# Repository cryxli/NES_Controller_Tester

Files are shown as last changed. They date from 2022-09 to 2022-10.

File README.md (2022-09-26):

# NES Controller Tester

 > When fixing and refurbishing S/NES controllers, I need a way to quickly test the buttons. Games are usually not that useful, since you have to start something before you can test all buttons. To save me fiddling with potentially buggy consoles, I desinged my own tester.
>
> ~ cryxli, August 2022

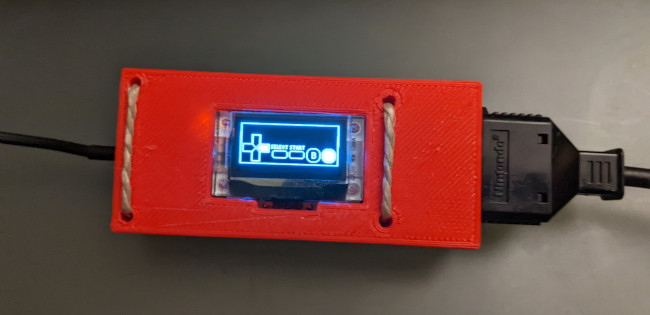
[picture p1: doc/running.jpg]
Running


Finished project showing some pressed buttons, powered by a USB power bank, held together with string.

## Project Overview

You do not have to go the extra mile to make the project modular. By doing so you save on Dupont headers, but have to scope with an increased risk of damaging the ESP.

### Repository

- ``/doc`` - Contains files for the documentation.
- ``/NES_controller_tester`` - Contains the [Arduino](https://www.arduino.cc) source code. Open this folder in the IDE.
- ``/pcb`` - Contains the [Sprint Layout 6](https://www.electronic-software-shop.com/lng/en/electronic-software/sprint-layout-60.html?language=en) design of the base plate.
- ``/scad`` - Contains the [OpenSCAD](https://openscad.org) design for the enclosure.

### Parts

- NES controller socket with straight pins
- [Heltec Wifi Kit 32, with OLED display](https://heltec-automation-docs.readthedocs.io/en/latest/esp32/quick_start.html)
- Straight and angled pin headers and sockets
- 5 pin Dupont connector
- 3 pin Dupont connector
- Dupont female crimps
- USB lead

### Tools

- Soldering equipment (iron, solder, flux)
- Pliers for Dupont crimps
- Computer with [Arduino](https://www.arduino.cc) IDE to flash the ESP
- NES controller and UBS power bank for testing

## S/NES Controller Pinout

NES and SNES controllers work exactly the same. Because both are keyed (they are asymmetrical) there is no need to distingush between front or back, socket or connector view.

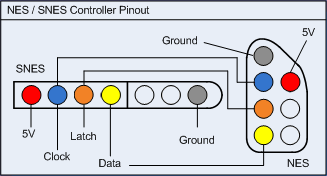
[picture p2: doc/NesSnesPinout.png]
Pinout


- ``RED`` := 5V
- ``GRAY`` := GND
- ``BLUE`` := Clock (active low)
- ``ORANGE`` := Latch (active high)
- ``YELLOW`` := Data (active low)
- ``WHITE`` := unused by standard controllers

"Active low" means a locigal ``1`` is represented by 0V. While with "active high" a logical ``1`` would be represented by about 3V or above.

## Protocol

The S/NES controllers use a serial protocol to transmit the state of the buttons to the console. That means a [Shift Register (PISO)](https://en.wikipedia.org/wiki/Shift_register#Parallel-in_serial-out_(PISO)) reads the state of the buttons and then sends them one by one over the DATA line to the console.

For that to happen the console must tell the controller to read the button states by setting LATCH high.

With every pulse of the CLOCK to low the next button state is set on the DATA line.

A button is pressed <=> Corresponding DATA is low.

## Shift Registers

The NES controllers have only one 8-bit shift register for their 8 buttons. The SNES controllers have 12 buttons and use two 8-bit shift registers chained together. 

The order in which the button states are transmitted differs

| Controller | T1  | T2  | T3 | T4 | T5  | T6 | T7 | T8 | T9  | T10 | T11 | T12 |
|:---|:---:|:---:|:---:|:-----:|:---:|:----:|:----:|:-----:|:---:|:---:|:---:|:---:|
| NES | A | B | Select | Start | Up  | Down | Left | Right | - | - | - | - |
| SNES | B | Y | Select | Start | Up  | Down | Left | Right | A | X | L | R |

[Shift registers](https://en.wikipedia.org/wiki/Shift_register) don't care how many times they are pulsed (CLOCK) to send the next bit. As long as they have data, they will answer before they eventually default to zeros.

Therefore, it should be possible to read both types of controller with the same piece of code that asks them for 16 bits of data.

## Display

[ESP8266](https://www.espressif.com/en/products/socs/esp8266) and later ESPs are overkill for reading S/NES controllers, but they constantly evolve. [Heltec Automation](https://heltec.org/) resently created a Devkit combined with an 128x64 pixel OLED display.

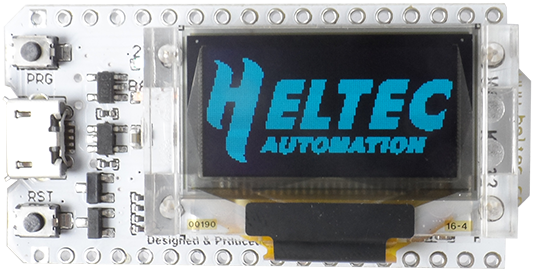
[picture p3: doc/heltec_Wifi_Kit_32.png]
Hiltec


They provide full support for the [Arduino](https://www.arduino.cc) development environment. Including a library to address the OLED display, complete with examples.

:bulb: [Setup Heltec ESP32 LoRa](https://heltec-automation-docs.readthedocs.io/en/latest/esp32/quick_start.html)

## Assembly

Most ESPs don't like it when you apply more than 3.3V on their input pins. To avoid that the controllers do that, let's drive them with only 3.3V from the board's voltage regulator.

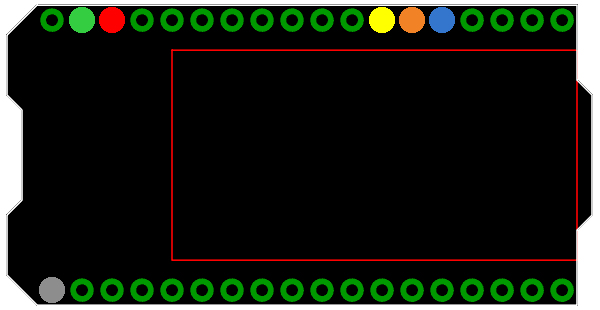
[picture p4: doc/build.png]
Build


The colored pins correspond to the colors used in the controller pinout, above. 

- ``GREEN`` = ``5V`` := Vin input voltage
- ``GRAY`` = ``GND`` := Ground or 0V reference for input voltage and connector circuit
- ``BLUE`` = ``18`` := Clock
- ``ORANGE`` = ``5`` := Latch
- ``YELLOW`` = ``17`` := Data
- ``RED`` = ``3V3`` := regulated 3.3V

The pins on the ESP board are not numbered like the legs of an IC. Look at a [pinout diagram](https://resource.heltec.cn/download/WiFi_Kit_32/WIFI_Kit_32_pinoutDiagram_V2.pdf) or the PCB, below.

## PCB

Note the gound pin next to the 5V input pin... I fried a board applying 5V using that pin as the 0V reference. To avoid future accidents I've drawn a base PCB in [Sprint Layout 6](https://www.electronic-software-shop.com/lng/en/electronic-software/sprint-layout-60.html?language=en). There is a free viewer on their site, too.

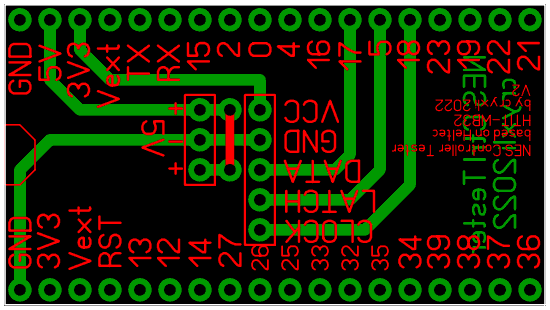
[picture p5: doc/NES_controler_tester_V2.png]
PCB


I also turned the design 180° to match the layout of the images above.

The idea is to have a 90° pin header expose the 5 connections for the controller and a 3 pin header for the power supply.

### 5V via USB

Whenever I cut off a USB lead and turn it into a 5V power supply for my projects, I add a 3 pin Dupond connector with center negative. By adding a link between the outer pins on the project/board, I do not have to worry about polarity anymore. 

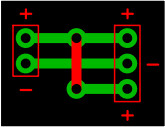
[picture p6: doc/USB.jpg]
5V USB


This comes from a time when I only used [Dupont](https://www.google.com/search?q=Dupont+connector) connectors that were *not* keyed.

## Enclosure

For the NES socket to fit in the 3d printed box, we have to cut off its studs at the bottom.

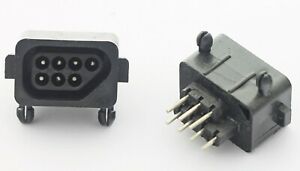
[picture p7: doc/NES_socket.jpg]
NES Socket


The design will hold it in place with the side tags only.

I use [OpenSCAD](https://openscad.org). Not only is it free, it also suits my way of designing best.

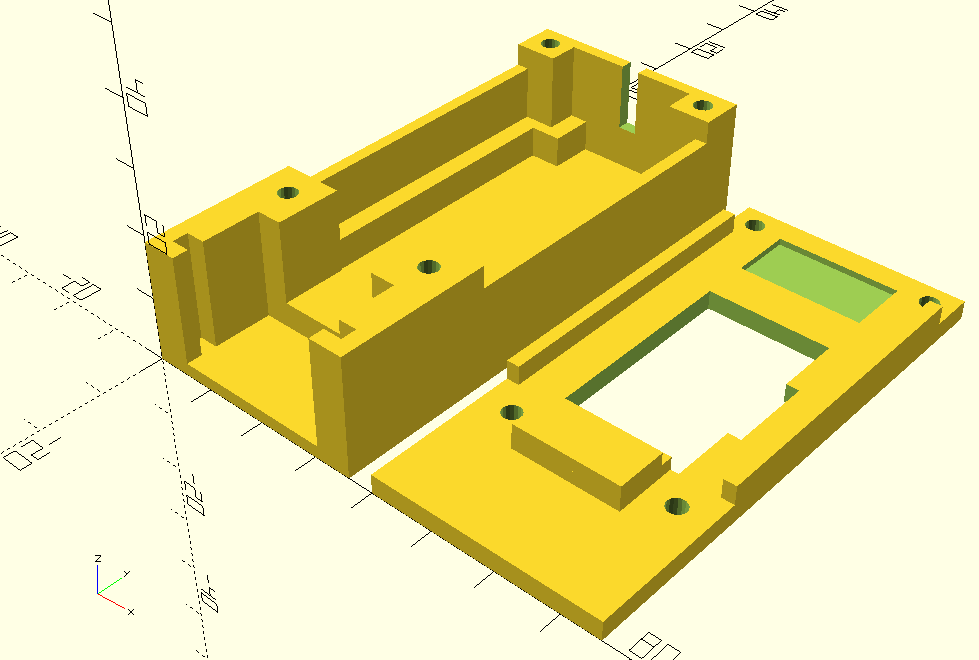
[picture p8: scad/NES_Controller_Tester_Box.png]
Enclosure


The lid is designed to register with the body. There should be less than 1/2 mm play with every component.

The box has holes for M3 bolts to hold it closed, but the friction fit of the interlocking lid is usually enough.

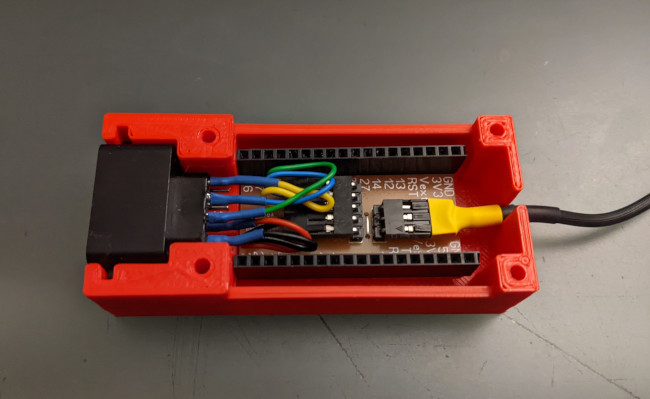
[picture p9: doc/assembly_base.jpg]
Assembly Base


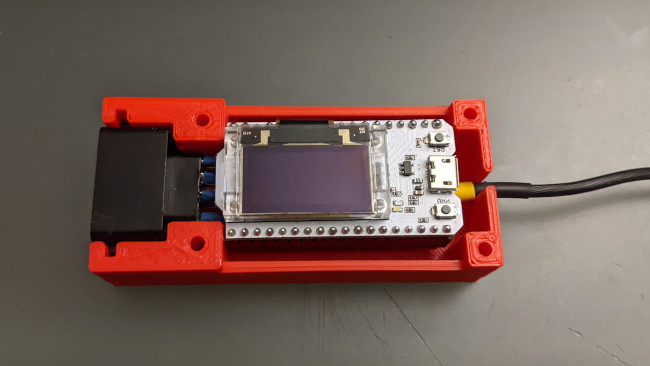
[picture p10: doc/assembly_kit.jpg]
Assembly Kit


Pay extra attention to the OLED display when closing the lid! The top glass layer is very thin and breaks easily. 

# Resources

Some helpful links:

- [Wifi Kit 32](https://heltec.org/project/wifi-kit-32/)
  - [Pinout](https://resource.heltec.cn/download/WiFi_Kit_32/WIFI_Kit_32_pinoutDiagram_V2.pdf)
- [Sprint Layout 6](https://www.electronic-software-shop.com/lng/en/electronic-software/sprint-layout-60.html?language=en)
  - [Viewer](https://www.electronic-software-shop.com/support/kostenlose-datei-viewer/)
- [OpenSCAD](https://openscad.org)
  - [User Manual](https://en.wikibooks.org/wiki/OpenSCAD_User_Manual)

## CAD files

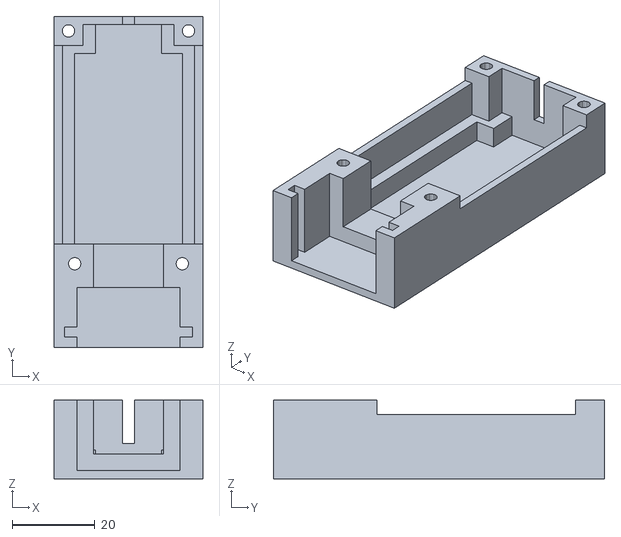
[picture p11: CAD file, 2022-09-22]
scad/NES_Controller_Tester_Box_body.stl
36.0 x 80.0 x 19.0

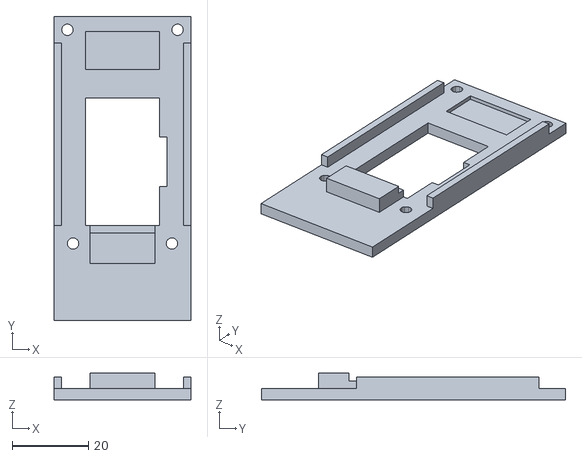
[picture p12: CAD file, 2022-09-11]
scad/NES_Controller_Tester_Box_lid.stl
36.0 x 80.0 x 7.00

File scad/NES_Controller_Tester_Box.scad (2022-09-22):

// -----------------------------------------
// NES Controller Tester
// by cryxli, August 2022
// -----------------------------------------

base_plate = 2;     // [mm] How strong to make the bottom of the box
depth = 25;         // [mm] How far the socket reaches into the box
height = 17;        // [mm] Height of the socket
oled_width = 19.5;  // [mm] Width of the OLED display
oled_length = 33.5; // [mm] Length od the OLED display
$fn = 18;           // [faces] Make circles 18 sided polys

// The body of the box
difference() {
	union() {
		// base
		cube([36,depth+48+2+5,base_plate]);
		
		// left side of socket
		cube([5.5,2.5,base_plate+height]);
		cube([2.5,10,base_plate+height]);
		translate([0,5,0]) cube([5.5,depth-5,base_plate+height]);
		translate([0,14.5,0]) cube([9.5,depth-14.5,base_plate+height]);
		
		// right side of socket
		translate([30.5,0,0]) {
			cube([5.5,2.5,base_plate+height]);
			translate([3,0,0]) cube([2.5,10,base_plate+height]);
			translate([0,5,0]) cube([5.5,depth-5,base_plate+height]);
			translate([-4,14.5,0]) cube([9.5,depth-14.5,base_plate+height]);
		}
		// bottom support for socket
		translate([0,14.5,0]) cube([36,depth-14.5,base_plate+4]);
		
		// back of box
		translate([0,depth+53,0]) cube([36,2,base_plate+height]);
		translate([0,depth+48,0]) cube([7,7,base_plate+height]);
		translate([29,depth+48,0]) cube([7,7,base_plate+height]);
		
		// side
		cube([2,depth+48+2+5,base_plate+height-3.5]);
		translate([0,7,0]) cube([5,depth+48,base_plate+5]);
		// opposite side
		translate([34,0,0]) cube([2,depth+48+2+5,base_plate+height-3.5]);
		translate([31,7,0]) cube([5,depth+48,base_plate+5]);

		// back stop for PCB
		translate([0,depth+46,0]) cube([10,9,base_plate+5]);
		translate([26,depth+46,0]) cube([10,9,base_plate+5]);
	}
	
	// M3 holes behind the socket
	translate([5,depth-4.75,-1]) cylinder(d=3, h=base_plate+height+2);
	translate([31,depth-4.75,-1]) cylinder(d=3, h=base_plate+height+2);
	// M3 holes at the end of the box
	translate([2+1.5,depth+48+2+1.5,-1]) cylinder(d=3, h=base_plate+height+2);
	translate([31+1.5,depth+48+2+1.5,-1]) cylinder(d=3, h=base_plate+height+2);
	
	// slit for USB lead
	translate([(36-3)/2,depth+48+2+5-3,height/2]) cube([3,4,height]);
}


// The lid
translate([40,0,0]) difference() {
	union() {
		// base
		cube([36,depth+48+2+5,3]);
		// register and hold-down for socket
		translate([(36-17)/2,15,0]) cube([17,8,3+4]);
		// with register for ESP
		translate([(36-17)/2,15,0]) cube([17,10,3+2]);
		
		// interlocking sides (0.5mm gap is intentional)
		translate([0,depth,0]) cube([2,48,6]);
		translate([36-2,depth,0]) cube([2,48,6]);
	}
	// space for the micro USB connector and buttons
	translate([(36-oled_width)/2,depth+48+5-12,2]) cube([oled_width,10,2]);

	// hole for OLED display and its ribbon
	translate([(36-oled_width)/2,depth,-1]) cube([oled_width,oled_length,5]);
	translate([(36-oled_width)/2+oled_width-1,depth + (oled_length-13)/2,-1]) cube([3,13,5]);

	// M3 holes behind the socket
	translate([5,depth-4.75,-1]) cylinder(d=3, h=5);
	translate([31,depth-4.75,-1]) cylinder(d=3, h=5);
	// M3 holes at the end of the box
	translate([2+1.5,depth+48+2+1.5,-1]) cylinder(d=3, h=5);
	translate([31+1.5,depth+48+2+1.5,-1]) cylinder(d=3, h=5);
}

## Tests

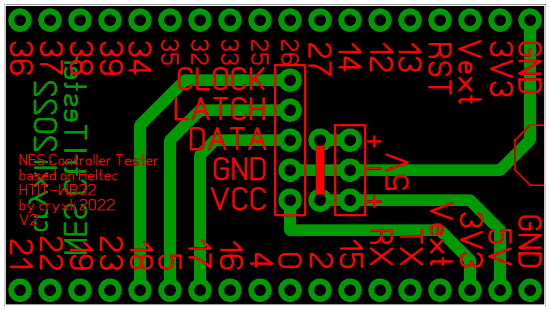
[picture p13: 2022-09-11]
pcb/NES_controler_tester_V2.png

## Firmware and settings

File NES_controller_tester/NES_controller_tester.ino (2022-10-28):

// -------------------------------------------------
// NES Controller Tester, v2.0
// by cryxli, August 2022
// 
// Based on a Heltec Wifi Kit 32 with a 128x64 pixel
// OLED display.
//
// This version supports NES and SNES controllers.
// -------------------------------------------------
#include "Arduino.h"
#include "heltec.h"

// include our bitmaps for the controller layout and buttons
#include "nes.h"
#include "snes.h"

// pins for communication with controller
//      5V          red
//      GND         black
#define DATA  17 // yellow
#define LATCH  5 // blue
#define CLOCK 18 // green

// define some delays [ms]
#define LATCH_DELAY 5
#define PULSE_DELAY 1
#define CLOCK_DELAY 5
#define DATA_DELAY 5
#define LOOP_DELAY 20

// bitmap masks for the NES buttons
#define NES_A      1<<7
#define NES_B      1<<6
#define NES_SELECT 1<<5
#define NES_START  1<<4
#define NES_UP     1<<3
#define NES_DOWN   1<<2
#define NES_LEFT   1<<1
#define NES_RIGHT  1<<0

// bitmap masks for the SNES buttons
#define SNES_B      1<<11
#define SNES_Y      1<<10
#define SNES_SELECT 1<<9
#define SNES_START  1<<8
#define SNES_UP     1<<7
#define SNES_DOWN   1<<6
#define SNES_LEFT   1<<5
#define SNES_RIGHT  1<<4
#define SNES_A      1<<3
#define SNES_X      1<<2
#define SNES_L      1<<1
#define SNES_R      1<<0

// you can set LoRa band directly, e.g. 868E6,915E6
#define BAND 868E6 

void setup() {
    // define pins
    pinMode(DATA, INPUT);
    pinMode(LATCH, OUTPUT);
    pinMode(CLOCK, OUTPUT);
    // set default state
    digitalWrite(LATCH, LOW);
    digitalWrite(CLOCK, HIGH);

    // init OLED etc.
    Heltec.begin(
        true  /* DisplayEnable Enable*/, 
        false /* LoRa Enable         */, 
        true  /* Serial Enable       */, 
        false /* LoRa use PABOOST    */, 
        BAND  /* LoRa RF working band*/
    );
}

/**
 * Quickly change the state of an output pin, then revert to stand-by.
 */
void pulseWire(int wire, bool pulse) {
    if (pulse == 1) {
        digitalWrite(wire, HIGH);
        delay(PULSE_DELAY);
        digitalWrite(wire, LOW);
    } else {
        digitalWrite(wire, LOW);
        delay(PULSE_DELAY);
        digitalWrite(wire, HIGH);
    }
}

void loop() {
    // have controller read button states
    pulseWire(LATCH, 1);
    delay(DATA_DELAY);

    //  NES buttons: A, B, SELECT, START, UP, DOWN, LEFT, RIGHT
    // SNES buttons: B, Y, SELECT, START, UP, DOWN, LEFT, RIGHT, A, X, L, R
    int buttons = 0;
    for(int index = 1<<15; index > 0; index = index >> 1) {
        buttons = (buttons << 1) + 1 - digitalRead(DATA);
        pulseWire(CLOCK, 0);
        delay(DATA_DELAY);
    }
    // for debugging
    // Serial.print("Buttons: ");
    // Serial.println(buttons);

    // display the result
    if (buttons & 15 > 0) {
        displayNoControllerConnected();
    } else if (buttons & 255 > 0) {
        displayNesButtons(buttons>>8);
    } else {
        displaySnesButtons(buttons>>4);
    }

    delay(LOOP_DELAY);
}

/**
 * "All" buttons are pressed, therefore no controller is connected. Show a
 * hint to connect a controller.
 */
void displayNoControllerConnected() {
    // reset display buffer
    Heltec.display -> clear();
    // draw the empty controller layout
//    Heltec.display -> drawXbm(0, 0, NES_Layout_width, NES_Layout_height, NES_Layout_bits);
    // show hint
    Heltec.display -> drawString(10, 5, "Connect a controller...");

    Heltec.display -> drawString(10, 25, "Support for NES and");
    Heltec.display -> drawString(10, 35, "SNES controllers.");

    Heltec.display -> drawString(10, 50, "v2.0");
    Heltec.display -> drawString(80, 50, "by cryxli");
    
    // update display
    Heltec.display -> display();
}

/**
 * Graphically show which NES buttons are pressed
 */
void displaySnesButtons(int buttons) {
    // display pressed buttons; reset display buffer
    Heltec.display -> clear();
    // draw the empty controller layout
    Heltec.display -> drawXbm(0, 0, SNES_Layout_width, SNES_Layout_height, SNES_Layout_bits);

    // highlight pressed buttons
    if ((buttons & SNES_UP) > 0) {
        Heltec.display -> drawXbm(17, 17, NES_up_width, NES_up_height, NES_up_bits);
    }
    if ((buttons & SNES_LEFT) > 0) {
        Heltec.display -> drawXbm(3, 29, NES_left_width, NES_left_height, NES_left_bits);
    }
    if ((buttons & SNES_RIGHT) > 0) {
        Heltec.display -> drawXbm(22, 29, NES_right_width, NES_right_height, NES_right_bits);
    }
    if ((buttons & SNES_DOWN) > 0) {
        Heltec.display -> drawXbm(17, 35, NES_down_width, NES_down_height, NES_down_bits);
    }
    if ((buttons & SNES_SELECT) > 0) {
        Heltec.display -> fillRect(44, 37, 16, 6);
    }
    if ((buttons & SNES_START) > 0) {
        Heltec.display -> fillRect(66, 37, 16, 6);
    }
    if ((buttons & SNES_L) > 0) {
        Heltec.display -> fillRect(0, 0, 12, 6);
    }
    if ((buttons & SNES_R) > 0) {
        Heltec.display -> fillRect(116, 0, 12, 6);
    }
    if ((buttons & SNES_Y) > 0) {
        Heltec.display -> fillRect(89, 27, 9, 9);
    }
    if ((buttons & SNES_X) > 0) {
        Heltec.display -> fillRect(101, 15, 9, 9);
    }
    if ((buttons & SNES_B) > 0) {
        Heltec.display -> fillRect(101, 39, 9, 9);
    }
    if ((buttons & SNES_A) > 0) {
        Heltec.display -> fillRect(113, 27, 9, 9);
    }
    // done, update display
    Heltec.display -> display();
}

/**
 * Graphically show which SNES buttons are pressed
 */
void displayNesButtons(int buttons) {
    // display pressed buttons; reset display buffer
    Heltec.display -> clear();
    // draw the empty controller layout
    Heltec.display -> drawXbm(0, 0, NES_Layout_width, NES_Layout_height, NES_Layout_bits);
    // highlight pressed buttons
    if ((buttons & NES_UP) > 0) {
        Heltec.display -> drawXbm(17, 17, NES_up_width, NES_up_height, NES_up_bits);
    }
    if ((buttons & NES_LEFT) > 0) {
        Heltec.display -> drawXbm(3, 29, NES_left_width, NES_left_height, NES_left_bits);
    }
    if ((buttons & NES_RIGHT) > 0) {
        Heltec.display -> drawXbm(22, 29, NES_right_width, NES_right_height, NES_right_bits);
    }
    if ((buttons & NES_DOWN) > 0) {
        Heltec.display -> drawXbm(17, 35, NES_down_width, NES_down_height, NES_down_bits);
    }
    if ((buttons & NES_SELECT) > 0) {
        Heltec.display -> fillRect(44, 37, 16, 6);
    }
    if ((buttons & NES_START) > 0) {
        Heltec.display -> fillRect(66, 37, 16, 6);
    }
    if ((buttons & NES_B) > 0) {
        Heltec.display -> drawXbm(89, 33, NES_a_width, NES_a_height, NES_a_bits);
    }
    if ((buttons & NES_A) > 0) {
        Heltec.display -> drawXbm(109, 33, NES_a_width, NES_a_height, NES_a_bits);
    }
    // done, update display
    Heltec.display -> display();
}

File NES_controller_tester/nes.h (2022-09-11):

// -------------------------------------------------
// NES Controller Tester
// by cryxli, August 2022
// 
// Based on a Heltec Wifi Kit 32 with a 128x64 pixel
// OLED display.
//
// This file contains the bitmaps for the NES
// controller layout including pressed buttons.
// -------------------------------------------------

// empty controller layout
#define NES_Layout_width 128
#define NES_Layout_height 53

const unsigned char NES_Layout_bits[] PROGMEM = {
    0xff,0xff,0xff,0xff,0xff,0xff,0xff,0xff,0xff,0xff,0xff,0xff,0xff,0xff,0xff,0xff,
    0x01,0x00,0x00,0x00,0x00,0x00,0x00,0x00,0x00,0x00,0x00,0x00,0x00,0x00,0x00,0x80,
    0x01,0x00,0x00,0x00,0x00,0x00,0x00,0x00,0x00,0x00,0x00,0x00,0x00,0x00,0x00,0x80,
    0x01,0x00,0x00,0x00,0x00,0x00,0x00,0x00,0x00,0x00,0x00,0x00,0x00,0x00,0x00,0x80,
    0x01,0x00,0x00,0x00,0x00,0x00,0x00,0x00,0x00,0x00,0x00,0x00,0x00,0x00,0x00,0x80,
    0x01,0x00,0x00,0x00,0x00,0x00,0x00,0x00,0x00,0x00,0x00,0x00,0x00,0x00,0x00,0x80,
    0x01,0x00,0x00,0x00,0x00,0x00,0x00,0x00,0x00,0x00,0x00,0x00,0x00,0x00,0x00,0x80,
    0x01,0x00,0x00,0x00,0x00,0x00,0x00,0x00,0x00,0x00,0x00,0x00,0x00,0x00,0x00,0x80,
    0x01,0x00,0x00,0x00,0x00,0x00,0x00,0x00,0x00,0x00,0x00,0x00,0x00,0x00,0x00,0x80,
    0x01,0x00,0x00,0x00,0x00,0x00,0x00,0x00,0x00,0x00,0x00,0x00,0x00,0x00,0x00,0x80,
    0x01,0x00,0x00,0x00,0x00,0x00,0x00,0x00,0x00,0x00,0x00,0x00,0x00,0x00,0x00,0x80,
    0x01,0x00,0x00,0x00,0x00,0x00,0x00,0x00,0x00,0x00,0x00,0x00,0x00,0x00,0x00,0x80,
    0x01,0x00,0x00,0x00,0x00,0x00,0x00,0x00,0x00,0x00,0x00,0x00,0x00,0x00,0x00,0x80,
    0x01,0x00,0x00,0x00,0x00,0x00,0x00,0x00,0x00,0x00,0x00,0x00,0x00,0x00,0x00,0x80,
    0x01,0x00,0x00,0x00,0x00,0x00,0x00,0x00,0x00,0x00,0x00,0x00,0x00,0x00,0x00,0x80,
    0x01,0x80,0xff,0x03,0x00,0x00,0x00,0x00,0x00,0x00,0x00,0x00,0x00,0x00,0x00,0x80,
    0x01,0x80,0x00,0x02,0x00,0x00,0x00,0x00,0x00,0x00,0x00,0x00,0x00,0x00,0x00,0x80,
    0x01,0x80,0x00,0x02,0x00,0x00,0x00,0x00,0x00,0x00,0x00,0x00,0x00,0x00,0x00,0x80,
    0x01,0x80,0x00,0x02,0x00,0x00,0x00,0x00,0x00,0x00,0x00,0x00,0x00,0x00,0x00,0x80,
    0x01,0x80,0x00,0x02,0x00,0x00,0x00,0x00,0x00,0x00,0x00,0x00,0x00,0x00,0x00,0x80,
    0x01,0x80,0x00,0x02,0x00,0x00,0x00,0x00,0x00,0x00,0x00,0x00,0x00,0x00,0x00,0x80,
    0x01,0x80,0x00,0x02,0x00,0x00,0x00,0x00,0x00,0x00,0x00,0x00,0x00,0x00,0x00,0x80,
    0x01,0x80,0x00,0x02,0x00,0x00,0x00,0x00,0x00,0x00,0x00,0x00,0x00,0x00,0x00,0x80,
    0x01,0x80,0x00,0x02,0x00,0x00,0x00,0x00,0x00,0x00,0x00,0x00,0x00,0x00,0x00,0x80,
    0x01,0x80,0x00,0x02,0x00,0x00,0x00,0x00,0x00,0x00,0x00,0x00,0x00,0x00,0x00,0x80,
    0x01,0x80,0x00,0x02,0x00,0x00,0x00,0x00,0x00,0x00,0x00,0x00,0x00,0x00,0x00,0x80,
    0x01,0x80,0x00,0x02,0x00,0x00,0x00,0x00,0x00,0x00,0x00,0x00,0x00,0x00,0x00,0x80,
    0xf9,0xff,0x00,0xfe,0x3f,0x00,0x00,0x00,0x00,0x00,0x00,0x00,0x00,0x00,0x00,0x80,
    0x09,0x00,0x01,0x01,0x20,0x76,0x39,0x39,0xec,0x64,0x0e,0x00,0x00,0x00,0x00,0x80,
    0x09,0x00,0x82,0x00,0x20,0x11,0x89,0x12,0x42,0xaa,0x04,0x00,0x00,0x00,0x00,0x80,
    0x09,0x00,0x44,0x00,0x20,0x32,0x99,0x10,0x44,0x6e,0x04,0x00,0x00,0x00,0x00,0x80,
    0x09,0x00,0x28,0x00,0x20,0x14,0x89,0x12,0x48,0xaa,0x04,0xf0,0x0f,0x00,0xff,0x80,
    0x09,0x00,0x10,0x00,0x20,0x73,0x3b,0x11,0x46,0xaa,0x04,0x0c,0x30,0xc0,0x00,0x83,
    0x09,0x00,0x28,0x00,0x20,0x00,0x00,0x00,0x00,0x00,0x00,0x02,0x40,0x20,0x00,0x84,
    0x09,0x00,0x44,0x00,0x20,0x00,0x00,0x00,0x00,0x00,0x00,0x01,0x80,0x10,0x00,0x88,
    0x09,0x00,0x82,0x00,0x20,0xf0,0xff,0x0f,0xfc,0xff,0x03,0x01,0x80,0x10,0x00,0x88,
    0x09,0x00,0x01,0x01,0x20,0x08,0x00,0x10,0x02,0x00,0x84,0xc0,0x03,0x09,0x08,0x90,
    0xf9,0xff,0x00,0xfe,0x3f,0x04,0x00,0x20,0x01,0x00,0x88,0x40,0x04,0x09,0x14,0x90,
    0x01,0x80,0x00,0x02,0x00,0x04,0x00,0x20,0x01,0x00,0x88,0x40,0x04,0x09,0x22,0x90,
    0x01,0x80,0x00,0x02,0x00,0x04,0x00,0x20,0x01,0x00,0x88,0xc0,0x03,0x09,0x22,0x90,
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
};

// LEFT button pressed
#define NES_left_width 16
#define NES_left_height 7

const unsigned char NES_left_bits[] PROGMEM = {
    0xFC,0x0F,
    0xFC,0x1F,
    0xFC,0x3F,
    0xFC,0x7F,
    0xFC,0x3F,
    0xFC,0x1F,
    0xFC,0x0F
};

// RIGHT button pressed
#define NES_right_width 16
#define NES_right_height 7

const unsigned char NES_right_bits[] PROGMEM = {
    0xF0, 0x3F,
    0xF8, 0x3F,
    0xFC, 0x3F,
    0xFE, 0x3F,
    0xFC, 0x3F,
    0xF8, 0x3F,
    0xF0, 0x3F,
};

// UP button pressed
#define NES_up_width 8
#define NES_up_height 13

const unsigned char NES_up_bits[] PROGMEM = {
    0x7F,
    0x7F,
    0x7F,
    0x7F,
    0x7F,
    0x7F,
    0x7F,
    0x7F,
    0x7F,
    0x7F,
    0x3E,
    0x1C,
    0x08
};

// DOWN button pressed
#define NES_down_width 8
#define NES_down_height 13

const unsigned char NES_down_bits[] PROGMEM = {
    0x08,
    0x1C,
    0x3E,
    0x7F,
    0x7F,
    0x7F,
    0x7F,
    0x7F,
    0x7F,
    0x7F,
    0x7F,
    0x7F,
    0x7F
};

// A or B button pressed
#define NES_a_width 16
#define NES_a_height 14

const unsigned char NES_a_bits[] PROGMEM = {
    0xF8, 0x07,
    0xFE, 0x1F, 
    0xFE, 0x1F, 
    0xFF, 0x3F,
    0xFF, 0x3F,
    0xFF, 0x3F,
    0xFF, 0x3F,
    0xFF, 0x3F,
    0xFF, 0x3F,
    0xFF, 0x3F,
    0xFF, 0x3F,
    0xFE, 0x1F, 
    0xFE, 0x1F, 
    0xF8, 0x07
};

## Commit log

2022-09-11 Initial commit.
    [NES_Controller_Tester_Box.scad, NES_Controller_Tester_Box_body.stl, NES_Controller_Tester_Box_lid.stl]
2022-09-11 More explanations in the Arduino code.
2022-09-11 OpenSCAD clean-up.
    [NES_Controller_Tester_Box.scad]
2022-09-16 Added pictures of assembly process.
2022-09-20 USB 2pin Dupond explained. Or not.
    [NES_Controller_Tester_Box.scad]
2022-09-22 Update SCAD to center PCB.
    [NES_Controller_Tester_Box.scad, NES_Controller_Tester_Box_body.stl]
2022-10-28 Updated Arduino code to support NES and SNES. The layout is choosen bepending on the read button pattern.
